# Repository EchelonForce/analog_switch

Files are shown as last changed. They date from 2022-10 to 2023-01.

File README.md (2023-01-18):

# Eurorack Analog Switch Module

This is a design for a eurorack module that puts an analog switch in the audio path.

Full writeup here: https://www.robotdialogs.com/2023/01/eurorack-analog-switch-module.html

This work is licensed under a Creative Commons Attribution-NonCommercial-ShareAlike 4.0 International License. https://creativecommons.org/licenses/by-nc-sa/4.0/

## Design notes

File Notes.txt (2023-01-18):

https://tinyurl.com/2ox46lup
https://tinyurl.com/2k9ec4zy - added led
https://tinyurl.com/2fqhma4g - tidy
https://tinyurl.com/2jy94jec - Added switch

Issues on v1:
 - Clips inputs over 7.8V. Probably something internal in the DG418LDJ.
   Could attenuate the input and amplify the output with a few design changes.

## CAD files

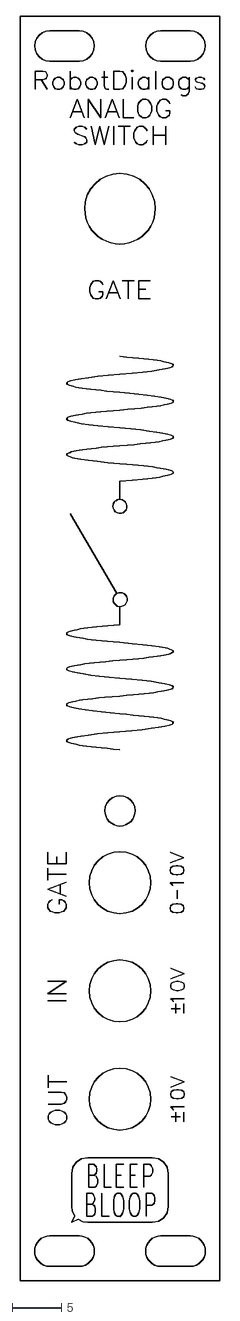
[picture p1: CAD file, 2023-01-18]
front_panel_v1/analog_switch_v1_front_panel_v1_engraving.dxf
20.2 x 128.4

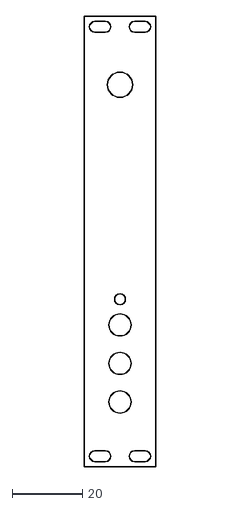
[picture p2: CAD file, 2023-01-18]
front_panel_v1/analog_switch_v1_front_panel_v1_no_engraving.dxf
20.3 x 128.5

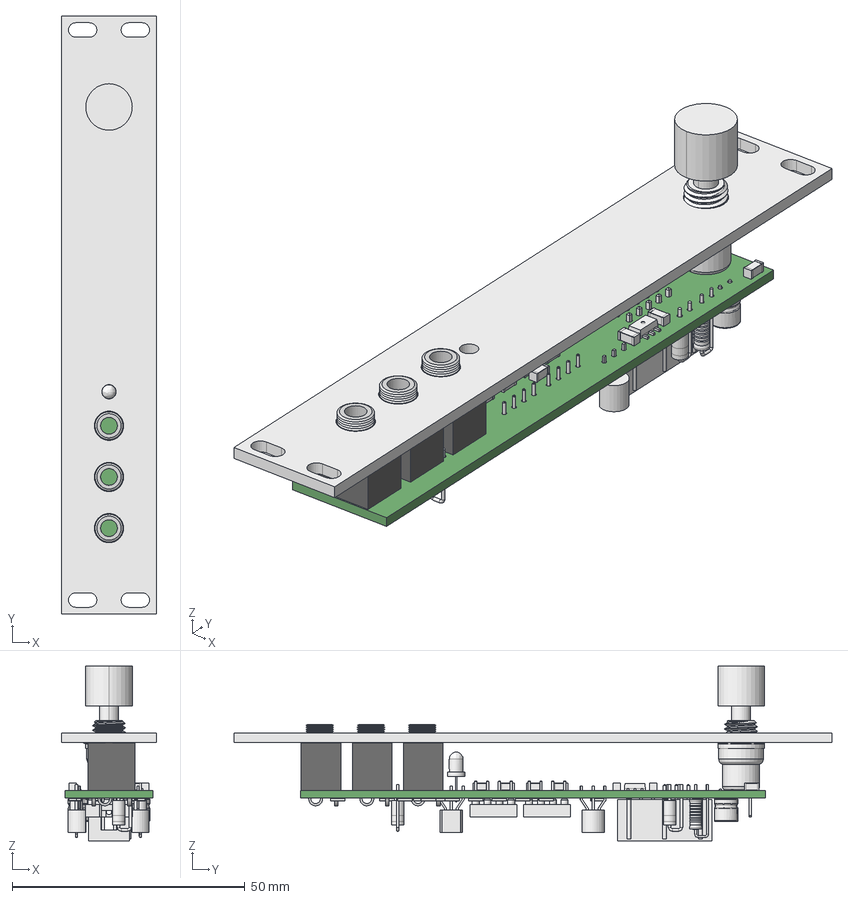
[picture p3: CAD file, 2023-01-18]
front_panel_v1/analog_switch_v1_front_panel_v1.FCStd
20.3 x 128.5 x 37.5 mm
analog_switch_v1 PCB

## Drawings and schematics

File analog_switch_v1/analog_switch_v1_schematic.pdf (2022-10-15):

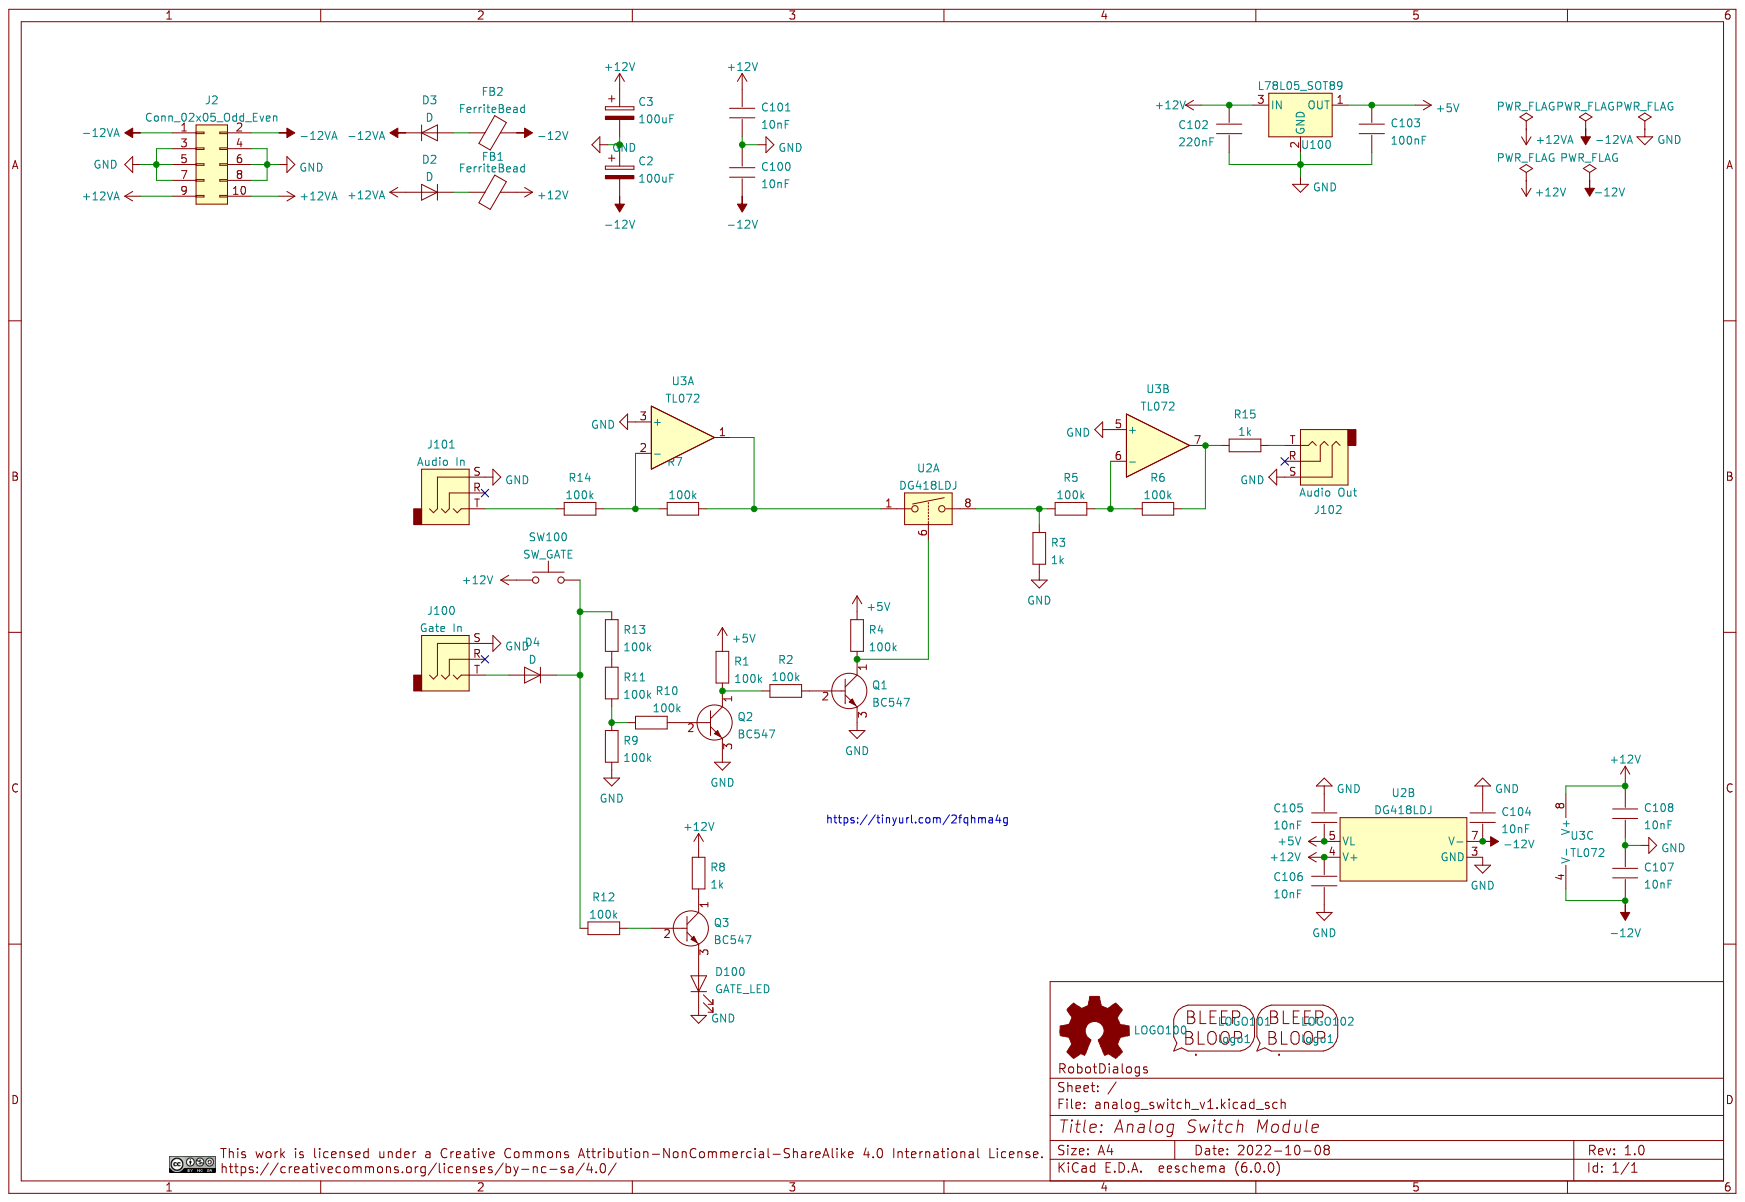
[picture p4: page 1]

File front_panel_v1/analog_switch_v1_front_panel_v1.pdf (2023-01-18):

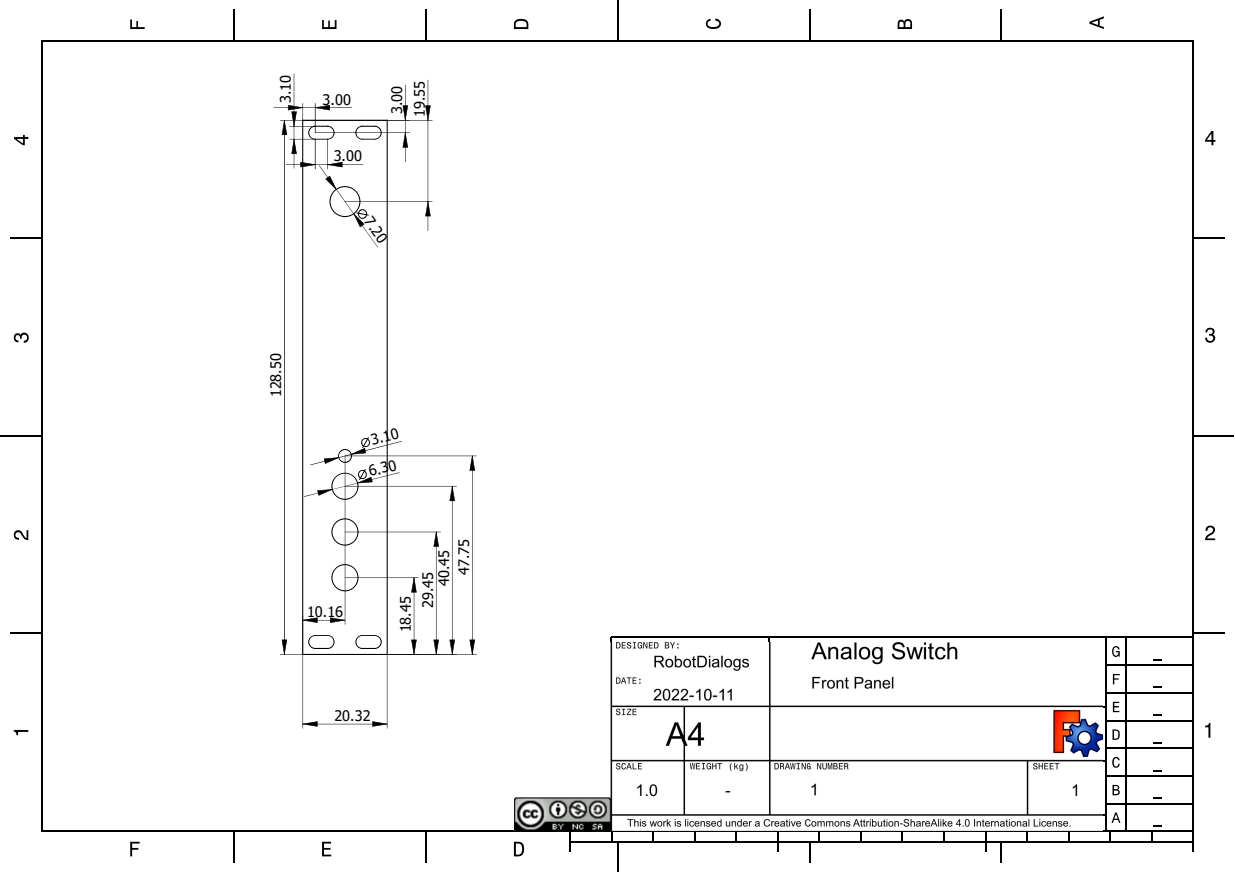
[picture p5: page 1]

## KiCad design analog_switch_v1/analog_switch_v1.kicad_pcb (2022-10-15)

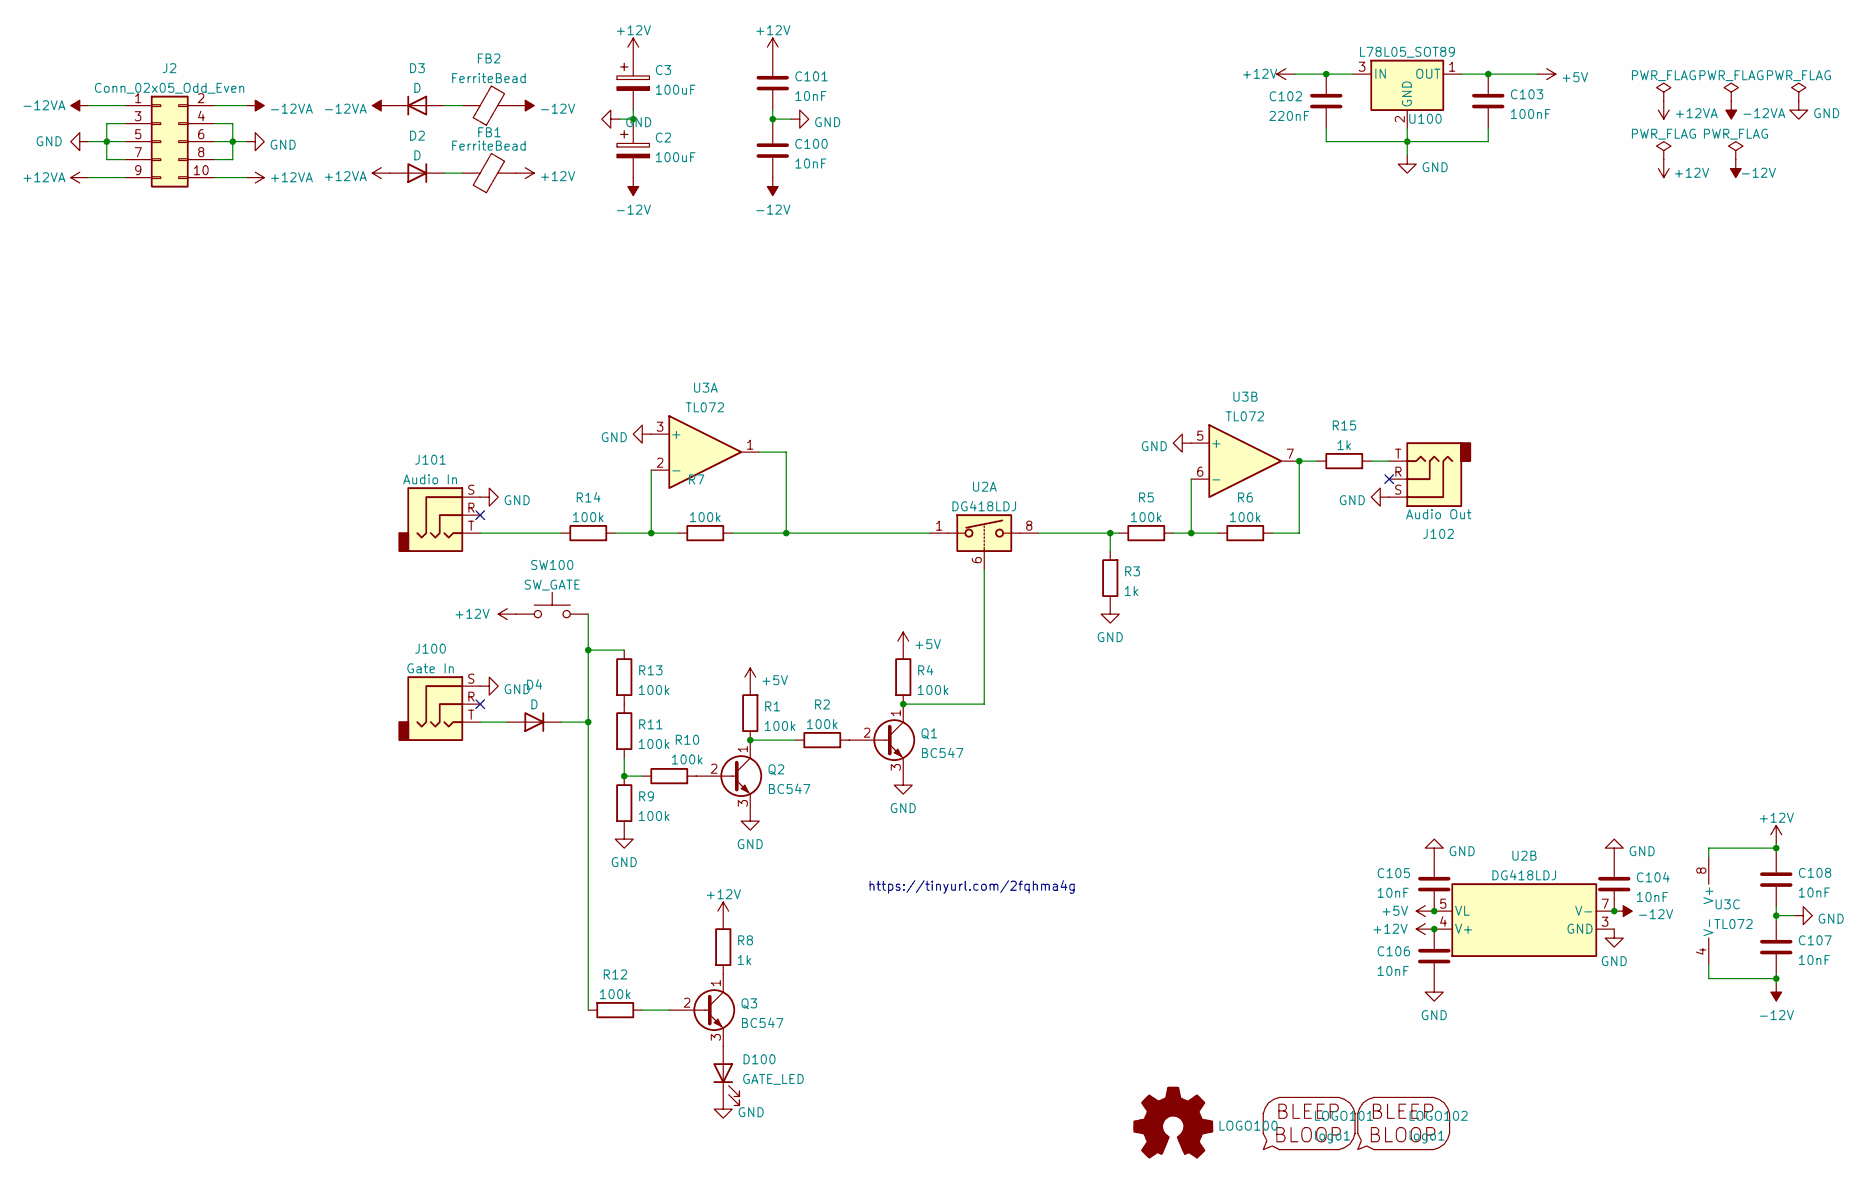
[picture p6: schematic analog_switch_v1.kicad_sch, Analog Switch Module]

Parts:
C2, C3: 100uF; CP_Radial_D5.0mm_P2.50mm
C100, C101, C104, C105, C106, C107, C108: 10nF; C_1206_3216Metric_Pad1.33x1.80mm_HandSolder
C102: 220nF; C_1206_3216Metric_Pad1.33x1.80mm_HandSolder
C103: 100nF; C_1206_3216Metric_Pad1.33x1.80mm_HandSolder
D2, D3, D4: D; D_A-405_P2.54mm_Vertical_KathodeUp
D100: GATE_LED; LED_D3.0mm
FB1, FB2: FerriteBead; L_Axial_L6.6mm_D2.7mm_P2.54mm_Vertical_Vishay_IM-2
J2: Conn_02x05_Odd_Even; IDC-Header_2x05_P2.54mm_Vertical
J100: Gate In; Jack_3.5mm_MJ-355W_Vertical
J101: Audio In; Jack_3.5mm_MJ-355W_Vertical
J102: Audio Out; Jack_3.5mm_MJ-355W_Vertical
LOGO100: Logo_Open_Hardware_Small; OSHW-Symbol_6.7x6mm_SilkScreen
LOGO101: logo1; Logo1
LOGO102: logo1; Logo2
Q1, Q2, Q3: BC547; TO-92_Inline_Wide
R1, R2, R4, R5, R6, R7, R9, R10, R11, R12, R13, R14: 100k; R_1206_3216Metric_Pad1.30x1.75mm_HandSolder
R3, R8, R15: 1k; R_1206_3216Metric_Pad1.30x1.75mm_HandSolder
SW100: SW_GATE; SW_PS1024ALRED
U2: DG418LDJ; DIP-8_W7.62mm_Socket_LongPads
U3: TL072; DIP-8_W7.62mm_Socket_LongPads
U100: L78L05_SOT89; SOT-89-3

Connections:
+5V: C103.1, C105.2, R1.2, R4.1, U2.5 (VL), U100.1 (OUT)
+12V: C3.1, C101.1, C102.1, C106.1, C108.1, FB1.2, R8.1, SW100.1, U2.4 (V+), U3.8 (V+), U100.3 (IN)
+12VA: D2.2 (A), J2.9, J2.10
-12V: C2.2, C100.2, C104.2, C107.2, FB2.2, U2.7 (V-), U3.4 (V-)
-12VA: D3.1 (K), J2.1, J2.2
GND: C2.1, C3.2, C100.1, C101.2, C102.2, C103.2, C104.1, C105.1, C106.2, C107.1, C108.2, D100.1 (K), J2.3, J2.4, J2.5, J2.6, J2.7, J2.8, J100.S, J101.S, J102.S, Q1.3 (E), Q2.3 (E), R3.1, R9.2, U2.3 (GND), U3.3 (+), U3.5 (+), U100.2 (GND)
unnamed: D2.1 (K), FB1.1
unnamed: D3.2 (A), FB2.1
unnamed: D4.1 (K), R12.2, R13.1, SW100.2
unnamed: D4.2 (A), J100.T
unnamed: D100.2 (A), Q3.3 (E)
unnamed: J101.T, R14.1
unnamed: J102.T, R15.2
unnamed: Q1.1 (C), R4.2, U2.6
unnamed: Q1.2 (B), R2.2
unnamed: Q2.1 (C), R1.1, R2.1
unnamed: Q2.2 (B), R10.2
unnamed: Q3.1 (C), R8.2
unnamed: Q3.2 (B), R12.1
unnamed: R3.2, R5.1, U2.8
unnamed: R11.1, R13.2
unnamed: R9.1, R10.1, R11.2
unnamed: R7.2, U2.1, U3.1
unnamed: R7.1, R14.2, U3.2 (-)
unnamed: R5.2, R6.1, U3.6 (-)
unnamed: R6.2, R15.1, U3.7

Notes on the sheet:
https://tinyurl.com/2fqhma4g

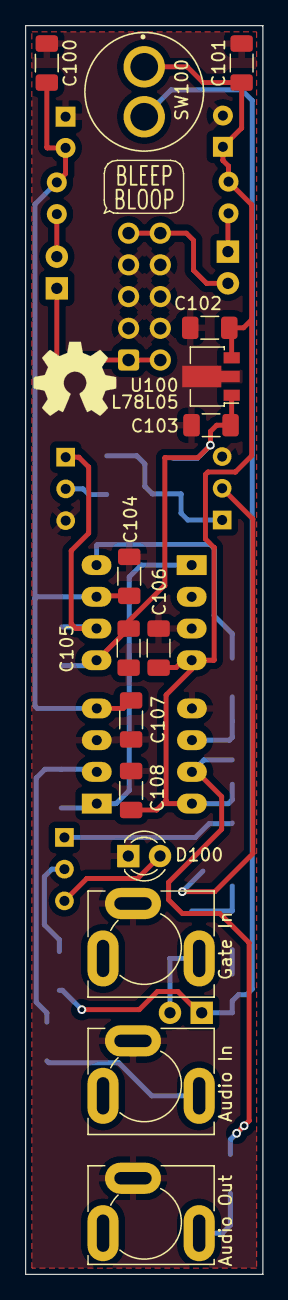
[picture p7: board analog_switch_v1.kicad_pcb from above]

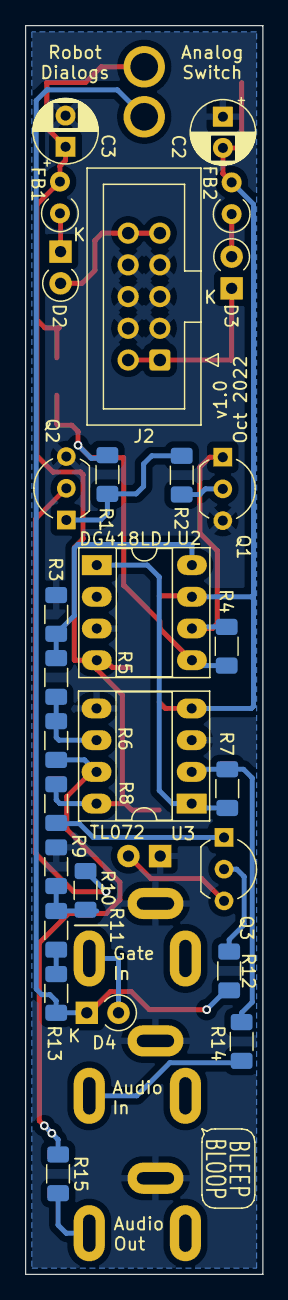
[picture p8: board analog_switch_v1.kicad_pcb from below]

Board: 2 copper layers, 19.0 x 100.0 mm, 46 parts (28 on the bottom side), 26 nets.

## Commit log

2022-10-08 Schematic and PCB draft, not completed
    [analog_switch_v1.kicad_pcb, analog_switch_v1.kicad_sch]
2022-10-10 Geographic re-annotate and silkscreen cleanup
    [analog_switch_v1.kicad_pcb, analog_switch_v1.kicad_sch]
2022-10-10 Panelized v1
    [analog_switch_v1_panelized.kicad_pcb]
2022-10-15 Tried to fix mystery fusion pcb issue
    These boards had some issue when I ordered them, something in the
    fusion pcb service didn't work right but I don't know what... So I
    tweaked the silkscreen a bit and fixed the grid/drill origin. The
    single pcb works in their system but it still complained about the
    panelized version. I just submitted it anyways, we'll see if they find
    some more specific issue.
    [analog_switch_v1.kicad_pcb, analog_switch_v1_panelized.kicad_pcb]
2022-10-15 Schematic pdf
2023-01-18 Add front panel CAD v1
    [analog_switch_v1_front_panel_v1.FCStd, analog_switch_v1_front_panel_v1_engraving.dxf, analog_switch_v1_front_panel_v1_no_engraving.dxf]
